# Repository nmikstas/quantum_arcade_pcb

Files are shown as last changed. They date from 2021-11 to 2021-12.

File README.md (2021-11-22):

# quantum_arcade_pcb
Reproduction of the Atari Quantum Arcade PCB. The PCB is designed with Kicad. This project is now complete and verified working!

# Folder Structure
* BOM - Bill of materials
* gerbers - Gerber files
* Quantum_1B_GAL - Design and programming files for the GAL IC located at location 1B
* quantum_arcade_pcb - Kicad design files

# PCB Specifications
* Layers: 2
* Dimensions: 293mm X 531mm
* Different PCB Design: 1
* PCB Thickness: 1.6mm
* Surface Finish: HASL
* Castellated Holes: No
* Copper Weight: 1oz.

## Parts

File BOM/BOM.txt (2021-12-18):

Part_ID                                                              QTY     DESC             Part_Num

R20, R22, R48, R56, R57, R75, R76                                    7       Not Populated   N/A
C5,  C6,  C7,  C22, C23, C24                                         6       Not Populated   N/A
C_9, E_9                                                             2       Not Populated   N/A

C2,   C3,   C9,   C10,  C11,  C14,  C15,  C16,  C17,  C18,           75      .1uf            Digikey 399-4454-1-ND
C19,  C20,  C26,  C27,  C28,  C31,  C33,  C34,  C35,  C36,
C39,  C40,  C49,  C64,  C65,  C67,  C68,  C69,  C70,  C71,
C72,  C73,  C75,  C78,  C79,  C81,  C91,  C92,  C93,  C94,
C95,  C96,  C97,  C98,  C99,  C100, C101, C102, C103, C104,
C105, C106, C107, C108, C109, C110, C111, C112, C113, C114,
C115, C116, C117, C118, C119, C120, C121, C122, C123, C124,
C125, C126, C127, C128, C129
C52,  C53,  C54,  C55,  C56,  C57,  C58,  C59,  C60,  C62,           11      1uf 50V          Digikey 1572-1280-ND
C74
C41,  C83,  C84,  C85,  C86,  C87,  C88,  C89,  C90                  9       .01uf            Digikey 399-4452-1-ND
C13,  C30,  C32,  C76                                                4       100pf            Digikey BC1057CT-ND
C12,  C29,  C38,  C77                                                4       39pf             Digikey P9633-ND
C44,  C46,  C82                                                      3       100uf 35V        Digikey 1572-1309-ND
C45,  C48,  C47                                                      3       22uf 25V         Digikey 1572-1393-ND
C51,  C61                                                            2       1000pf 100V      Digikey 399-4450-1-ND
C8,   C25                                                            2       .047uF           Digikey BC3089-ND
C4                                                                   1       .01uF            Digikey 399-14040-1-ND
C21                                                                  1       .0018uF          Digikey 445-173483-1-ND
C37                                                                  1       150pF            Digikey 399-4213-ND
C42                                                                  1       10pF             Digikey 399-14082-ND
C63                                                                  1       220pf            Digikey 1004PHCT-ND
C80                                                                  1       .022uf           Digikey 399-C412C223K1R5TA-ND
C130                                                                 1       .047uf           Digikey 399-4512-1-ND

CR3, CR4, CR6                                                        3       1N100            Digikey 2368-1N4002-ND
CR1                                                                  1       1N914            Digikey 1N914FS-ND
CR5                                                                  1       1N754A           Digikey 2368-1N754A-ND
CR7                                                                  1       Blue LED         Digikey VAOL-5701SBY4-ND

L2, L3, L4                                                           1       1uH              Digikey M10137-ND
L1                                                                   1       100uH            Digikey 78F101J-TR-RCCT-ND

Q7,  Q9, Q10, Q11, Q13, Q14, Q17                                     7       2N3904           Digikey 2N3904TAFSCT-ND
Q8,  Q12                                                             2       2N3906           Digikey 2N3906TAFSCT-ND
Q15, Q16                                                             2       2N6044           Digikey BDX53BG-ND

R53,  R80,  R82,  R119, R129, R147, R148, R153, R155, R156,          29      1k               Digikey 1.0KQBK-ND
R157, R158, R159, R166, R167, R168, R169, R170, R171, R172,
R176, R205, R210, R214, R218, R219, R220, R221, R222
R40,  R46,  R67,  R73,  R83,  R118, R120, R121, R122, R123,          21      10k              Digikey 10KQBK-ND
R124, R125, R126, R127, R128, R143, R163, R173, R177, R178,
R215
R142, R188, R189, R190, R191, R192, R193, R194, R195, R196,          19      4.7k             Digikey 4.7KQBK-ND
R197, R198, R199, R200, R201, R202, R203, R216, R217
R32,  R33,  R38,  R51,  R59,  R62,  R63, R137, R138, R139,           16      470              Digikey 470KQBK-ND
R149, R151, R152, R160, R161, R162
R36,  R44,  R45,  R50,  R64,  R69,  R70,  R77, R131, R133,           12      2.2k             Digikey 2.2KQBK-ND
R135, R141
R30,  R31,  R58,  R85,  R86,  R89,  R93,  R95,  R96,  R106,          12      7.5K             Digikey 7.50KXBK-ND
R87,  R91
R110, R111, R112, R113, R114, R115, R116, R117, R134, R145           10      3.3k             Digikey 3.3KQBK-ND
R180, R181, R182, R183, R184, R185, R186, R187                       8       100K             Digikey 100KQBK-ND
R204, R206, R207, R208, R209, R211, R212, R213                       8       220k             Digikey 100KQBK-ND
R37,  R39,  R52,  R65,  R66,  R78,  R79,  R97                        8       3.9k             Digikey 3.9KQBK-ND
R90,  R94,  R224, R225, R226                                         5       100              Digikey 100QBK-ND
R42,  R43,  R68,  R72                                                4       10K POT          Digikey 3386P-103-ND‎
R164, R165, R179, R223                                               4       220              Digikey 220QBK-ND
R35,  R54,  R61                                                      3       680              Digikey 680QBK-ND
R26,  R27,  R55                                                      3       820              Digikey 820QBK-ND
R47,  R74                                                            2       2K POT           Digikey 3386P-202-ND‎
R88,  R92                                                            2       200 POT          Digikey 3386P-201LF-ND
R130, R132                                                           2       1.8k             Digikey 1.8kQBK-ND
R34,  R60                                                            2       2.7k             Digikey 2.7kQBK-ND
R41,  R71                                                            2       5.6k             Digikey 5.6kQBK-ND
R81,  R175                                                           2       15K              Digikey 15kQBK-ND
R49                                                                  1       1.5k             Digikey 1.5kQBK-ND
R84                                                                  1       560              Digikey 560QBK-ND
R108                                                                 1       270              Digikey 270QBK-ND
R136                                                                 1       6.8k             Digikey 6.8kQBK-ND
R140                                                                 1       1.2k             Digikey 1.2kQBK-ND
R144                                                                 1       22k              Digikey 22kQBK-ND
R146                                                                 1       510              Digikey 510QBK-ND
R174                                                                 1       68k              Digikey 68kQBK-ND

RV1, RV2                                                             2       VDR              Alan-1 VDR Replacement

SW1, SW2                                                             2       SW_DIP_x08       Digikey 450-1215-ND

TP+15V1,  TP-15V1,  TP+5V01,  TP+5V02, TP+6V81, TPAUD1, TPAUD2,      19      Test Point       Digikey WM6456-ND
TPBLU1,   TPGND1,   TPGND2,   TPGND3,  TPGRN1,  TPRED1, TP12MHZ,
TPRESET1, TPRESET2, TPWDDIS1, TPXOUT1, TPYOUT1

VR1                                                                  1       L7815            Digikey 296-21624-5-ND
VR2                                                                  1       L7915            Digikey 497-7295-5-ND‎

Y1                                                                   1       12.096MHz        Digikey X429-ND

E_2,   E_3,    F_2,    F_3,  H/J_2, H/J_3, K_2, K_3, L_2, L_3        10      8KX8_ROM
D_5,   D_6,    E_5,    E_6,  M_2,   M_3,   N_2, N_3                  8       2KX8_RAM
A_7,   A_8,    B_7,    B_8,  C_7,   C_8                              6       LS194
D/E_4, E/F_4,  P_2,    P_3,  N_1,   P_1                              6       LS245
A_10,  D/E_11, D/E_12, D_10, M/N_12                                  5       TL082
L_5,   M_5,    M_6,    M_7,  R_6                                     5       LS161
B_5,   C_5,    E_7,    P_10, A_5                                     5       LS157
F_8,   L_9,    J_7,    J_8,  D_7                                     5       LS175
B_11,  B_12,   C_11,   C_12                                          4       MC1495L
L_4,   P_5,    R_2,    R_10                                          4       LS74
M_9,   N_9,    E_1,    F_1                                           4       LS244
F_5,   K_7,    K_8                                                   3       LS32
F_6,   H_7,    P_4                                                   3       LS00
M_8,   N_8,    P_9                                                   3       LS191
A_3,   C_3                                                           2       LM324
B_2/3, D_2/3                                                         2       POKEY
B_9,   F/H_9                                                         2       AM6012
B_10,  E_10                                                          2       LF13201
D_1,   H/J_4                                                         2       LS138
F/H_4, J_10                                                          2       LS04
J_4,   P_6                                                           2       LS02
K_6,   K_9                                                           2       LS109
L_8,   N_6                                                           2       S02
R_4,   R_5                                                           2       LS393
N_10,  P_11                                                          2       4584B
D_8,   N_5                                                           2       LS273
B_1                                                                  1       GAL16V8A
B_6                                                                  1       AVG
D_9                                                                  1       DAC_8
F_7                                                                  1       S289
H_5                                                                  1       LS174
H_6                                                                  1       S129             Alan-1 ROM Replacement
H_8                                                                  1       LS399
J_5                                                                  1       S74
J_6                                                                  1       LS42
J_9                                                                  1       LS260
K/L_1                                                                1       68000
K_4                                                                  1       LS08
K_5                                                                  1       LS27
K_10                                                                 1       S86
L_6                                                                  1       LS14
L_7                                                                  1       S260
M_4                                                                  1       06
N_4                                                                  1       S32
N_7                                                                  1       LS164
P_7                                                                  1       LS163
P_8                                                                  1       S04
R_3                                                                  1       X2212

MISC
-------------------
Pastic Tabs                                                          2       Tabs             Digikey RPC1553-ND      
Heatsink                                                             2       Heatsink         Digikey A10756-ND

IC Sockets
-------------------
8  pin    5
14 pin    37
16 pin    36
18 pin    1
20 pin    15
24 pin    9
28 pin    10
40 pin    3
64 pin    1

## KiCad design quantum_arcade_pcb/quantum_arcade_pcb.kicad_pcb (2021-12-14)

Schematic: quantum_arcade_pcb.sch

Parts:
A_3: LM324A; DIP14
A_5: LS157A; DIP16
A_7, A_8: LS194; DIP16
A_10: 082; DIP8
B_1: 137290; DIP20
B_2/3: POKEY; DDIP40
B_5: LS157B; DIP16
B_6: AVG; DDIP40
B_7, B_8: LS194; DIP16
B_9: AM6012; DIP20
B_10: LF13201; DIP16
B_11, B_12: MC1495LB; DIP14
C2, C3, C9, C10, C11, C14, C15, C16, C17, C18, C19, C20, C26, C27, C28, C31, C33, C34, C35, C36, C39, C40: .1uF; GenComp
C4: .01uF; CapSmall
C5, C6, C22, C23: ?; GenComp
C7, C24: ?; CapSmall
C8, C25: .047uF; CapInt
C12, C29: 39pf; CapSmall
C13, C30, C32: 100pf; CapSmall
C21: .0018uF; CapSmall
C37: 150pF; CapSmall
C38: 39pF; CapSmall
C41: .01uF; GenComp
C42: 10pF; CapSmall
C44, C46: 100uf 35V; Cap2
C45, C48: 22uf 25V; Cap1
C47: 22uf 35V; Cap3
C49, C64, C65, C67, C68, C69, C70, C71, C72, C73, C75, C78, C79, C81, C91, C92, C93, C94, C95, C96, C97, C98, C99, C100, C101, C102, C103, C104, C105, C106, C107, C108, C109, C110, C111, C112, C113, C114, C115, C116, C117, C118, C119, C120, C121, C122, C123, C124, C125, C126, C127, C128, C129: .1uf; GenComp
C51, C61: 1000pf 100V; GenComp
C52, C53, C54, C55, C56, C57, C58, C59, C60, C62: 1uf 50V; Cap1
C63: 220pf; GenComp
C74: 1uf; Cap1
C76: 100pf 100V; CapSmall
C77: 39pf 100V; CapSmall
C80: .022uf; GenComp
C82: 100uf 25V; Cap2
C83, C84, C85, C86, C87, C88, C89, C90: .01uf 25V; GenComp
C130: .047uf; GenComp
CR1: 1N914; Diode
CR3, CR4, CR6: 1N100; Diode
CR5: 1N754A; Diode
CR7: LED
C_3: LM324A; DIP14
C_5: LS157B; DIP16
C_7, C_8: LS194; DIP16
C_9: Spare16; DIP16
C_11, C_12: MC1495LA; DIP14
D/E_4: LS245; DIP20
D/E_11, D/E_12: 082; DIP8
D_1: LS138; DIP16
D_2/3: POKEY; DDIP40
D_5, D_6: 2KX8_RAM; DDIP24
D_7: LS175C; DIP16
D_8: LS273; DIP20
D_9: DAC_8; DIP16
D_10: 082; DIP8
E/F_4: LS245; DIP20
E_1: LS244A; DIP20
E_2, E_3: 8KX8_ROM; DIP28
E_5, E_6: 2KX8_RAM; DDIP24
E_7: LS157B; DIP16
E_9: Spare16; DIP16
E_10: LF13201; DIP16
F/H_4: LS04; DIP14
F/H_9: AM6012; DIP20
F_1: LS244B; DIP20
F_2, F_3: 8KX8_ROM; DIP28
F_5: LS32; DIP14
F_6: LS00; DIP14
F_7: S289; DIP16
F_8: LS175; DIP16
H/J_2, H/J_3: 8KX8_ROM; DIP28
H/J_4: LS138; DIP16
H_5: LS174; DIP16
H_6: S129; DIP16
H_7: LS00; DIP14
H_8: LS399; DIP16
J20: J20; EdgeCon
J_4: LS02; DIP14
J_5: S74; DIP14
J_6: LS42; DIP16
J_7: LS175A; DIP16
J_8: LS175B; DIP16
J_9: LS260; DIP14
J_10: LS04; DIP14
K/L_1: 68000; DIP64
K_2, K_3: 8KX8_ROM; DIP28
K_4: LS08; DIP14
K_5: LS27; DIP14
K_6, K_9: LS109; DIP16
K_7, K_8: LS32; DIP14
K_10: S86; DIP14
L1: 100uH; Ind
L2, L3, L4: 1uH; Ind
L_2, L_3: 8KX8_ROM; DIP28
L_4: LS74; DIP14
L_5: LS161; DIP16
L_6: LS14; DIP14
L_7: S260; DIP14
L_8: S02; DIP14
L_9: LS175; DIP16
M/N_12: TL082; DIP8
M_2, M_3: 2KX8_RAM; DDIP24
M_4: 06; DIP14
M_5, M_6, M_7: LS161; DIP16
M_8: LS191A; DIP16
M_9: LS244C; DIP20
N_1: LS245B; DIP20
N_2, N_3: 2KX8_RAM; DDIP24
N_4: S32; DIP14
N_5: LS273B; DIP20
N_6: S02; DIP14
N_7: LS164; DIP14
N_8: LS191A; DIP16
N_9: LS244C; DIP20
N_10: 4584B; DIP14
P_1: LS245A; DIP20
P_2, P_3: LS245C; DIP20
P_4: LS00; DIP14
P_5: LS74; DIP14
P_6: LS02; DIP14
P_7: LS163; DIP16
P_8: S04; DIP14
P_9: LS191A; DIP16
P_10: LS157B; DIP16
P_11: 4584B; DIP14
Q7, Q9, Q10, Q11, Q13, Q14, Q17: 2N3904; GenTrans
Q8, Q12: 2N3906; GenTrans
Q15, Q16: 2N6044; BigTrans
R20, R22, R56, R57: ?; GenComp
R26, R27, R55: 820; GenComp
R30, R31, R58, R85, R86, R89, R93, R95, R96, R106: 7.5K; GenComp
R32, R33, R38, R51, R59, R62, R63, R137, R138, R139, R149, R151, R152, R160, R161, R162: 470; GenComp
R34, R60: 2.7k; GenComp
R35, R54, R61: 680; GenComp
R36, R44, R45, R50, R64, R69, R70, R77, R131, R133, R135, R141: 2.2k; GenComp
R37, R39, R52, R65, R66, R78, R79: 3.9k; GenComp
R40, R46, R67, R73, R118, R120, R121, R122, R123, R124, R125, R126, R127, R128, R143, R163, R173, R177, R178, R215: 10k; GenComp
R41, R71: 5.6k; GenComp
R42, R43, R68, R72: 10k; PotBlk
R47, R74: 2K; PotBlk
R48, R75: 100k; GenComp
R49: 1.5k; GenComp
R53, R80, R119, R129, R147, R148, R153, R155, R156, R157, R158, R159, R166, R167, R168, R169, R170, R171, R172, R176, R205, R210, R214, R218, R219, R220, R221, R222: 1k; GenComp
R76, R140: 1.2k; GenComp
R81: 15K; GenComp
R82: 1K; GenComp
R83: 10K; GenComp
R84: 560; GenComp
R87, R91: 7.5k; GenComp
R88, R92: 200; PotBlk
R90, R94, R224, R225, R226: 100; GenComp
R97: 3.9K; GenComp
R108: 270; CapInt
R110, R111, R112, R113, R114, R115, R116, R117, R134, R145: 3.3k; GenComp
R130, R132: 1.8k; GenComp
R136: 6.8k; GenComp
R142, R188, R189, R190, R191, R192, R193, R194, R195, R196, R197, R198, R199, R200, R201, R202, R203, R216, R217: 4.7k; GenComp
R144: 22k; GenComp
R146: 510; GenComp
R164, R165, R179, R223: 220; GenComp
R174: 68k; GenComp
R175: 15k; GenComp
R180, R181, R182, R183, R184, R185, R186, R187: 100K; GenComp
R204, R206, R207, R208, R209, R211, R212, R213: 220k; GenComp
RV1, RV2: VDR; GenComp
R_2, R_10: LS74; DIP14
R_3: X2212; DIP18
R_4, R_5: LS393; DIP14
R_6: LS161; DIP16
SW1, SW2: SW_DIP_x08; DIP16
TP5V1, TP5V2, TP6.8V1, TP12M1: TP
TP+15V1: TP
TP-15V1: TP
TPAUD1, TPAUD2: TP
TPBLU1: TP
TPGND1, TPGND2, TPGND3: TP
TPGRN1: TP
TPRED1: TP
TPRESET1, TPRESET2: TP
TPWDDIS1: TP
TPXOUT1: TP
TPYOUT1: TP
VR1: L7815_; BigTrans
VR2: L7915_; BigTrans
Y1: 12.096MHz; Crystal

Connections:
1.5M: K_6.3 (K), K_6.13 (K), K_7.9, P_6.12, P_7.12 (QC), P_8.9
1HORIZCLK: C55.2, C85.2, J20.6, R112.2
1HORIZDIR: C53.2, C83.2, J20.H, R110.2
1VERTCLK: C59.2, C89.2, J20.5, R116.2
1VERTDIR: C57.2, C87.2, J20.F, R114.2
2HORIZCLK: C56.2, C86.2, J20.8, R113.2
2HORIZDIR: C54.2, C84.2, J20.C, R111.2
2VERTCLK: C60.2, C90.2, J20.7, R117.2
2VERTDIR: C58.2, C88.2, J20.D, R115.2
3M: L_7.12, N_7.8 (CLK), P_6.11, P_7.13 (QB)
6M: K/L_1.15 (CLK), L_7.3, P_5.3 (1CLK), P_5.11 (2CLK), P_7.14 (QA), R_2.3 (1CLK), R_2.11 (2CLK)
12M: A_7.11 (CK), A_8.11 (CK), B_7.11 (CK), B_8.11 (CK), C_7.11 (CK), C_8.11 (CK), K_6.4 (Cp), K_6.12 (Cp), K_9.4 (Cp), K_9.12 (Cp), L_5.2 (CLK), M_5.2 (CLK), M_6.2 (CLK), M_7.2 (CLK), M_8.14 (CK), P_7.2 (CLK), P_8.10, TP12M1.1, TP12M1.2
750KHZ: P_7.11 (QD), R_5.1 (1CK)
+5V: A_5.16 (VCC), A_7.16 (VCC), A_8.16 (VCC), B_1.20 (Vcc), B_2/3.17 (VCC), B_5.16 (VCC), B_6.37 (VDD), B_7.16 (VCC), B_8.16 (VCC), B_9.20 (VCC), C2.1, C5.2, C19.1, C22.2, C39.1, C71.2, C75.1, C82.1, C96.1, C97.1, C98.1, C99.1, C100.1, C101.1, C102.1, C103.1, C104.1, C105.1, C106.1, C107.1, C108.1, C109.1, C110.1, C111.1, C112.1, C113.1, C114.1, C115.1, C116.1, C117.1, C118.1, C119.1, C120.1, C121.1, C122.1, C123.1, C124.1, C125.1, C126.1, C127.1, C128.1, C129.1, CR6.1 (K), C_5.16 (VCC), C_7.16 (VCC), C_8.16 (VCC), C_9.14, D/E_4.20 (VCC), D_1.16 (VCC), D_2/3.17 (VCC), D_5.24 (VCC), D_6.24 (VCC), D_7.16 (VCC), D_8.20 (VCC), D_9.13 (V+), E/F_4.20 (VCC), E_1.20 (VCC), E_2.1 (VPP), E_2.27 (~PGM), E_2.28 (VCC), E_3.1 (VPP), E_3.27 (~PGM), E_3.28 (VCC), E_5.24 (VCC), E_6.24 (VCC), E_7.16 (VCC), E_9.14, F/H_4.14 (VCC), F/H_9.20 (VCC), F_1.20 (VCC), F_2.1 (VPP), F_2.27 (~PGM), F_2.28 (VCC), F_3.1 (VPP), F_3.27 (~PGM), F_3.28 (VCC), F_5.14 (VCC), F_6.14 (VCC), F_7.16 (VCC), F_8.16 (VCC), H/J_2.1 (VPP), H/J_2.27 (~PGM), H/J_2.28 (VCC), H/J_3.1 (VPP), H/J_3.27 (~PGM), H/J_3.28 (VCC), H/J_4.16 (VCC), H_5.16 (VCC), H_6.16 (VCC), H_7.14 (VCC), H_8.16 (VCC), J20.2, J20.21, J20.B, J20.Y, J_4.14 (VCC), J_5.14 (VCC), J_6.16 (VCC), J_7.16 (VCC), J_8.16 (VCC), J_9.14 (VCC), J_10.14 (VCC), K/L_1.14 (VCC), K/L_1.49 (VCC), K_2.1 (VPP), K_2.27 (~PGM), K_2.28 (VCC), K_3.1 (VPP), K_3.27 (~PGM), K_3.28 (VCC), K_4.14 (VCC), K_5.14 (VCC), K_6.16 (VCC), K_7.14 (VCC), K_8.14 (VCC), K_9.16 (VCC), K_10.14 (VCC), L_2.1 (VPP), L_2.27 (~PGM), L_2.28 (VCC), L_3.1 (VPP), L_3.27 (~PGM), L_3.28 (VCC), L_4.14 (VCC), L_5.16 (VCC), L_6.14 (VCC), L_7.14 (VCC), L_8.14 (VCC), L_9.16 (VCC), M/N_12.2 (-), M_2.24 (VCC), M_3.24 (VCC), M_4.14 (VCC), M_5.16 (VCC), M_6.16 (VCC), M_7.16 (VCC), M_8.16 (VCC), M_9.20 (VCC), N_1.20 (VCC), N_2.24 (VCC), N_3.24 (VCC), N_4.14 (VCC), N_5.20 (VCC), N_6.14 (VCC), N_7.14 (VCC), N_8.16 (VCC), N_9.20 (VCC), N_10.14 (VCC), P_1.20 (VCC), P_2.20 (VCC), P_3.20 (VCC), P_4.14 (VCC), P_5.14 (VCC), P_6.14 (VCC), P_7.16 (VCC), P_8.14 (VCC), P_9.16 (VCC), P_10.16 (VCC), P_11.14 (VCC), Q13.3 (C), Q17.3 (C), R145.2, R146.2, R149.2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
+6V: B_11.1, B_12.1, C32.1, C49.1, CR5.1 (K), C_11.1, C_12.1, R108.1, TP6.8V1.1, TP6.8V1.2
+10V: C74.1, J20.18, J20.E, M/N_12.8 (V+), R173.2
+15V: A_3.4 (V+), A_10.8 (VCC), B_10.13, B_11.2, B_12.2, C9.2, C11.2, C15.2, C18.1, C26.2, C28.2, C33.2, C36.1, C45.1, C92.1, C94.1, CR3.1 (K), C_3.4 (V+), D/E_11.8 (VCC), D/E_12.8 (VCC), D_10.8 (VCC), E_10.13, Q8.1 (E), R44.2, R45.2, R53.1, R69.2, R70.2, R80.1, R82.2, R95.1, R96.1, R108.2, TP+15V1.1, TP+15V1.2, VR1.3 (OUT)
+24V: C44.1, J20.3, J20.X, VR1.1 (IN)
-15V: A_3.11 (V-), A_10.4 (VSS), B_9.17 (V-), B_10.4, B_11.7, B_12.7, C3.2, C6.2, C10.2, C14.2, C16.2, C17.1, C20.2, C23.2, C27.2, C31.2, C34.2, C35.1, C40.1, C41.1, C48.2, C91.1, C93.1, CR4.2 (A), C_3.11 (V-), C_9.1, C_11.7, C_12.7, D/E_11.4 (VSS), D/E_12.4 (VSS), D_9.3 (V-), D_10.4 (VSS), E_9.1, E_10.4, F/H_9.17 (V-), TP-15V1.1, TP-15V1.2, VR2.3 (VO)
-24V: C46.2, C47.2, J20.4, J20.W, VR2.2 (VI)
A1: E_1.13 (I1b), K/L_1.29 (A1)
A2: E_1.11 (I0b), K/L_1.30 (A2)
A3: F_1.13 (I1b), K/L_1.31 (A3)
A4: F_1.11 (I0b), K/L_1.32 (A4)
A5: E_1.2 (I0a), K/L_1.33 (A5)
A6: F_1.2 (I0a), K/L_1.34 (A6)
A7: E_1.17 (I3b), K/L_1.35 (A7)
A8: E_1.4 (I1a), K/L_1.36 (A8)
A9: F_1.4 (I1a), K/L_1.37 (A9)
A10: F_1.17 (I3b), K/L_1.38 (A10)
A11: E_1.15 (I2b), K/L_1.39 (A11)
A12: F_1.6 (I2a), K/L_1.40 (A12)
A13: E_1.6 (I2a), K/L_1.41 (A13)
A14: F_1.15 (I2b), K/L_1.42 (A14)
A15: F_1.8 (I3a), K/L_1.43 (A15)
A16: D_1.3 (C), H/J_4.2 (B), K/L_1.44 (A16)
A17: H/J_4.3 (C), K/L_1.45 (A17)
A18: B_1.7, K/L_1.46 (A18)
A19: B_1.6, K/L_1.47 (A19)
A20: B_1.5, K/L_1.48 (A20)
A21: B_1.4, K/L_1.50 (A21)
A22: B_1.3, D_1.5 (~G2B), K/L_1.51 (A22)
A23: B_1.2, D_1.4 (~G2A), K/L_1.52 (A23), N_4.1
AB1: B_2/3.36 (A0), C_5.14 (4A), D_2/3.36 (A0), E_1.7 (O1b), E_2.10 (A0), E_3.10 (A0), E_7.14 (4A), F_2.10 (A0), F_3.10 (A0), H/J_2.10 (A0), H/J_3.10 (A0), K_2.10 (A0), K_3.10 (A0), L_2.10 (A0), L_3.10 (A0), M_2.8 (A0), M_3.8 (A0), N_2.8 (A0), N_3.8 (A0), R_3.6 (A0)
AB2: B_2/3.35 (A1), C_5.11 (3A), D_2/3.35 (A1), E_1.9 (O0b), E_2.9 (A1), E_3.9 (A1), E_7.11 (3A), F_2.9 (A1), F_3.9 (A1), H/J_2.9 (A1), H/J_3.9 (A1), K_2.9 (A1), K_3.9 (A1), L_2.9 (A1), L_3.9 (A1), M_2.7 (A1), M_3.7 (A1), N_2.7 (A1), N_3.7 (A1), R_3.5 (A1)
AB3: B_2/3.34 (A2), C_5.5 (2A), D_2/3.34 (A2), E_2.8 (A2), E_3.8 (A2), E_7.5 (2A), F_1.7 (O1b), F_2.8 (A2), F_3.8 (A2), H/J_2.8 (A2), H/J_3.8 (A2), K_2.8 (A2), K_3.8 (A2), L_2.8 (A2), L_3.8 (A2), M_2.6 (A2), M_3.6 (A2), N_2.6 (A2), N_3.6 (A2), R_3.4 (A2)
AB4: B_2/3.33 (A3), C_5.2 (1A), D_2/3.33 (A3), E_2.7 (A3), E_3.7 (A3), E_7.2 (1A), F_1.9 (O0b), F_2.7 (A3), F_3.7 (A3), H/J_2.7 (A3), H/J_3.7 (A3), K_2.7 (A3), K_3.7 (A3), L_2.7 (A3), L_3.7 (A3), M_2.5 (A3), M_3.5 (A3), N_2.5 (A3), N_3.5 (A3), R_3.3 (A3)
AB5: B_5.14 (4A), D_2/3.30 (~CSO), E_1.18 (O0a), E_2.6 (A4), E_3.6 (A4), F/H_4.9, F_2.6 (A4), F_3.6 (A4), H/J_2.6 (A4), H/J_3.6 (A4), K_2.6 (A4), K_3.6 (A4), L_2.6 (A4), L_3.6 (A4), M_2.4 (A4), M_3.4 (A4), N_2.4 (A4), N_3.4 (A4), R_3.2 (A4)
AB6: B_5.11 (3A), E_2.5 (A5), E_3.5 (A5), F_1.18 (O0a), F_2.5 (A5), F_3.5 (A5), H/J_2.5 (A5), H/J_3.5 (A5), K_2.5 (A5), K_3.5 (A5), L_2.5 (A5), L_3.5 (A5), M_2.3 (A5), M_3.3 (A5), N_2.3 (A5), N_3.3 (A5), R_3.1 (A5)
AB7: B_5.5 (2A), E_1.3 (O3b), E_2.4 (A6), E_3.4 (A6), F_2.4 (A6), F_3.4 (A6), H/J_2.4 (A6), H/J_3.4 (A6), K_2.4 (A6), K_3.4 (A6), L_2.4 (A6), L_3.4 (A6), M_2.2 (A6), M_3.2 (A6), N_2.2 (A6), N_3.2 (A6), R_3.17 (A6)
AB8: B_5.2 (1A), E_1.16 (O1a), E_2.3 (A7), E_3.3 (A7), F_2.3 (A7), F_3.3 (A7), H/J_2.3 (A7), H/J_3.3 (A7), K_2.3 (A7), K_3.3 (A7), L_2.3 (A7), L_3.3 (A7), M_2.1 (A7), M_3.1 (A7), N_2.1 (A7), N_3.1 (A7), R_3.16 (A7)
AB9: A_5.14 (4A), E_2.25 (A8), E_3.25 (A8), F_1.16 (O1a), F_2.25 (A8), F_3.25 (A8), H/J_2.25 (A8), H/J_3.25 (A8), K_2.25 (A8), K_3.25 (A8), L_2.25 (A8), L_3.25 (A8), M_2.23 (A8), M_3.23 (A8), N_2.23 (A8), N_3.23 (A8)
AB10: A_5.2 (1A), E_2.24 (A9), E_3.24 (A9), F_1.3 (O3b), F_2.24 (A9), F_3.24 (A9), H/J_2.24 (A9), H/J_3.24 (A9), K_2.24 (A9), K_3.24 (A9), L_2.24 (A9), L_3.24 (A9), M_2.22 (A9), M_3.22 (A9), N_2.22 (A9), N_3.22 (A9)
AB11: A_5.5 (2A), E_1.5 (O2b), E_2.21 (A10), E_3.21 (A10), F_2.21 (A10), F_3.21 (A10), H/J_2.21 (A10), H/J_3.21 (A10), K_2.21 (A10), K_3.21 (A10), L_2.21 (A10), L_3.21 (A10), M_2.19 (A10), M_3.19 (A10), N_2.19 (A10), N_3.19 (A10)
AB12: A_5.11 (3A), E_2.23 (A11), E_3.23 (A11), F_1.14 (O2a), F_2.23 (A11), F_3.23 (A11), H/J_2.23 (A11), H/J_3.23 (A11), K_2.23 (A11), K_3.23 (A11), L_2.23 (A11), L_3.23 (A11)
AB13: E_1.14 (O2a), E_2.2 (A12), E_3.2 (A12), F_2.2 (A12), F_3.2 (A12), H/J_2.2 (A12), H/J_3.2 (A12), K_2.2 (A12), K_3.2 (A12), L_2.2 (A12), L_3.2 (A12)
AB14: D_1.1 (A), F_1.5 (O2b)
AB15: D_1.2 (B), F_1.12 (O3a), H/J_4.1 (A)
AM1: C_5.12 (4Y), D_5.8 (A0), D_6.8 (A0), E_5.8 (A0), E_6.8 (A0)
AM2: C_5.9 (3Y), D_5.7 (A1), D_6.7 (A1), E_5.7 (A1), E_6.7 (A1)
AM3: C_5.7 (2Y), D_5.6 (A2), D_6.6 (A2), E_5.6 (A2), E_6.6 (A2)
AM4: C_5.4 (1Y), D_5.5 (A3), D_6.5 (A3), E_5.5 (A3), E_6.5 (A3)
AM5: B_5.12 (4Y), D_5.4 (A4), D_6.4 (A4), E_5.4 (A4), E_6.4 (A4)
AM6: B_5.9 (3Y), D_5.3 (A5), D_6.3 (A5), E_5.3 (A5), E_6.3 (A5)
AM7: B_5.7 (2Y), D_5.2 (A6), D_6.2 (A6), E_5.2 (A6), E_6.2 (A6)
AM8: B_5.4 (1Y), D_5.1 (A7), D_6.1 (A7), E_5.1 (A7), E_6.1 (A7)
AM9: A_5.12 (4Y), D_5.23 (A8), D_6.23 (A8), E_5.23 (A8), E_6.23 (A8)
AM10: A_5.4 (1Y), D_5.22 (A9), D_6.22 (A9), E_5.22 (A9), E_6.22 (A9)
AM11: A_5.7 (2Y), D_5.19 (A10), D_6.19 (A10), E_5.19 (A10), E_6.19 (A10)
AREF: A_3.5 (+), C78.2, C_3.10 (+), R204.2
AS: D_1.6 (G1), F/H_4.2, P_5.10 (~1PRE_), R_2.10 (~1PRE_)
AUDIO+: A_3.8, J20.13, R207.1, R208.2, TPAUD1.1, TPAUD1.2
BLUE: J20.17, R225.2, TPBLU1.1, TPBLU1.2
CNTR: K_7.4, K_9.6 (Q), L_7.11
COINAUX: J20.L, R159.2, R162.1
COINCONTL: C72.1, J20.15, Q15.2 (C)
COINCONTR: C73.1, J20.S, Q16.2 (C)
COINL: J20.J, R151.1, R155.2
COINR: J20.9, R152.1, R156.2
CS: B_2/3.31 (CS), D_2/3.31 (CS), J_4.10
D0: K/L_1.5 (D0), N_1.15 (B3)
D1: K/L_1.4 (D1), N_1.14 (B4)
D2: K/L_1.3 (D2), N_1.13 (B5)
D3: K/L_1.2 (D3), N_1.12 (B6)
D4: K/L_1.1 (D4), N_1.11 (B7)
D5: K/L_1.64 (D5), N_1.18 (B0)
D6: K/L_1.63 (D6), N_1.17 (B1)
D7: K/L_1.62 (D7), N_1.16 (B2)
D8: K/L_1.61 (D8), P_1.18 (B0)
D9: K/L_1.60 (D9), P_1.17 (B1)
D10: K/L_1.59 (D10), P_1.16 (B2)
D11: K/L_1.58 (D11), P_1.15 (B3)
D12: K/L_1.57 (D12), P_1.14 (B4)
D13: K/L_1.56 (D13), P_1.13 (B5)
D14: K/L_1.55 (D14), P_1.12 (B6)
D15: K/L_1.54 (D15), P_1.11 (B7)
DB0: B_2/3.38 (D0), D/E_4.11 (B7), D_2/3.38 (D0), F_7.4 (I0), M_9.14 (O2a), N_1.5 (A3), N_5.8 (D3), N_9.14 (O2a), P_3.16 (B2), R_3.12 (IO1)
DB1: B_2/3.39 (D1), D/E_4.12 (B6), D_2/3.39 (D1), F_7.6 (I1), M_9.12 (O3a), N_1.6 (A4), N_5.3 (D0), N_9.12 (O3a), P_3.14 (B4), R_3.13 (IO2)
DB2: B_2/3.40 (D2), D/E_4.13 (B5), D_2/3.40 (D2), F_7.10 (I2), M_9.16 (O1a), N_1.7 (A5), N_5.7 (D2), N_9.16 (O1a), P_3.12 (B6), R_3.14 (IO3)
DB3: B_2/3.2 (D3), D/E_4.14 (B4), D_2/3.2 (D3), F_7.12 (I3), M_9.18 (O0a), N_1.8 (A6), N_5.4 (D1), N_9.18 (O0a), P_3.11 (B7), R_3.15 (IO4)
DB4: B_2/3.3 (D4), D/E_4.15 (B3), D_2/3.3 (D4), M_9.5 (O2b), N_1.9 (A7), N_5.14 (D5), N_9.5 (O2b), P_3.13 (B5)
DB5: B_2/3.4 (D5), D/E_4.16 (B2), D_2/3.4 (D5), M_9.3 (O3b), N_1.2 (A0), N_5.13 (D4), N_9.3 (O3b), P_3.15 (B3)
DB6: B_2/3.5 (D6), D/E_4.17 (B1), D_2/3.5 (D6), M_9.7 (O1b), N_1.3 (A1), N_5.18 (D7), N_9.7 (O1b), P_3.17 (B1)
DB7: B_2/3.6 (D7), D/E_4.18 (B0), D_2/3.6 (D7), M_9.9 (O0b), N_1.4 (A2), N_5.17 (D6), N_9.9 (O0b), P_3.18 (B0)
DB8: E/F_4.11 (B7), P_1.2 (A0), P_2.16 (B2)
DB9: E/F_4.12 (B6), P_1.3 (A1), P_2.14 (B4)
DB10: E/F_4.13 (B5), P_1.4 (A2), P_2.12 (B6)
DB11: E/F_4.14 (B4), P_1.5 (A3), P_2.11 (B7)
DB12: E/F_4.15 (B3), P_1.6 (A4), P_2.13 (B5)
DB13: E/F_4.16 (B2), P_1.7 (A5), P_2.15 (B3)
DB14: E/F_4.17 (B1), P_1.8 (A6), P_2.17 (B1)
DB15: E/F_4.18 (B0), P_1.9 (A7), P_2.18 (B0)
DVG0: A_7.6 (D), A_8.6 (D), D/E_4.9 (A7), D_5.9 (D0), D_6.9 (D0)
DVG1: A_7.5 (C), A_8.5 (C), D/E_4.8 (A6), D_5.10 (D1), D_6.10 (D1)
DVG2: A_7.4 (B), A_8.4 (B), D/E_4.7 (A5), D_5.11 (D2), D_6.11 (D2)
DVG3: A_7.3 (A), A_8.3 (A), D/E_4.6 (A4), D_5.13 (D3), D_6.13 (D3)
DVG4: C_7.6 (D), C_8.6 (D), D/E_4.5 (A3), D_5.14 (D4), D_6.14 (D4)
DVG5: C_7.5 (C), C_8.5 (C), D/E_4.4 (A2), D_5.15 (D5), D_6.15 (D5)
DVG6: C_7.4 (B), C_8.4 (B), D/E_4.3 (A1), D_5.16 (D6), D_6.16 (D6)
DVG7: C_7.3 (A), C_8.3 (A), D/E_4.2 (A0), D_5.17 (D7), D_6.17 (D7)
DVG8: B_7.6 (D), B_8.6 (D), E/F_4.9 (A7), E_5.9 (D0), E_6.9 (D0)
DVG9: B_7.5 (C), B_8.5 (C), E/F_4.8 (A6), E_5.10 (D1), E_6.10 (D1)
DVG10: B_7.4 (B), B_8.4 (B), E/F_4.7 (A5), E_5.11 (D2), E_6.11 (D2)
DVG11: B_7.3 (A), B_8.3 (A), E/F_4.6 (A4), E_5.13 (D3), E_6.13 (D3)
DVG12: E/F_4.5 (A3), E_5.14 (D4), E_6.14 (D4), J_7.4 (D0), J_8.5 (D1)
DVG13: E/F_4.4 (A2), E_5.15 (D5), E_6.15 (D5), J_7.12 (D2), J_8.12 (D2)
DVG14: E/F_4.3 (A1), E_5.16 (D6), E_6.16 (D6), J_7.13 (D3), J_8.13 (D3)
DVG15: E/F_4.2 (A0), E_5.17 (D7), E_6.17 (D7), J_7.5 (D1), J_8.4 (D0)
DVX2: A_8.14 (QB), B_9.11 (B11), C_9.13
DVX3: A_8.15 (QA), B_9.10 (B10), C_8.7 (L), C_9.12
DVX4: B_9.9 (B9), C_8.12 (QD), C_9.11
DVX5: B_9.8 (B8), C_8.13 (QC), C_9.10
DVX6: B_9.7 (B7), C_8.14 (QB), C_9.9
DVX7: B_8.7 (L), B_9.6 (B6), C_8.15 (QA), C_9.8
DVX8: B_8.12 (QD), B_9.5 (B5), C_9.7
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

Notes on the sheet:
POWER INPUT
CLOCK
POWER-ON RESET AND WATCHDOG
MICROPROCESSOR
ADDRESS BUS BUFFERS
BIDIRECTIONAL DATA BUS BUFFERS
ADDRESS DECODERS
PROGRAM RAM
DATA TRANSFER ACK GENERATOR
CHECK THIS!!!
PROGRAM ROM
Y-Axis Output
NOT LOADED
X-Axis Output
DAC Reference And Bipolar Current Sources
COIN DOOR AND CONTROL PANEL INPUT
TRACK BALL INPUT
NON-VOLATILE MEMORY
COIN DOOR AND CONTROL PANEL OUTPUT
AUDIO OUTPUT
COLOR MEMORY AND OUTPUT
VECTOR MEMORY ARBITRATOR
VECTOR MEMORY
BIDIRECTIONAL VECTOR MEMORY DATA BUFFERS
VECTOR DATA SHIFTERS
OPCODE AND INTENSITY LATCHES
VECTOR ADDRESS CONTROLLER
STATE MACHINE
Z INTENSITY
VECTOR TIMER
INTENSITY CORRECTION
VECTOR HALT FLAG
VECTOR FLAG
CENTER FLAG
NORMALIZATION FLAG
VECTOR SCALING
UNUSED

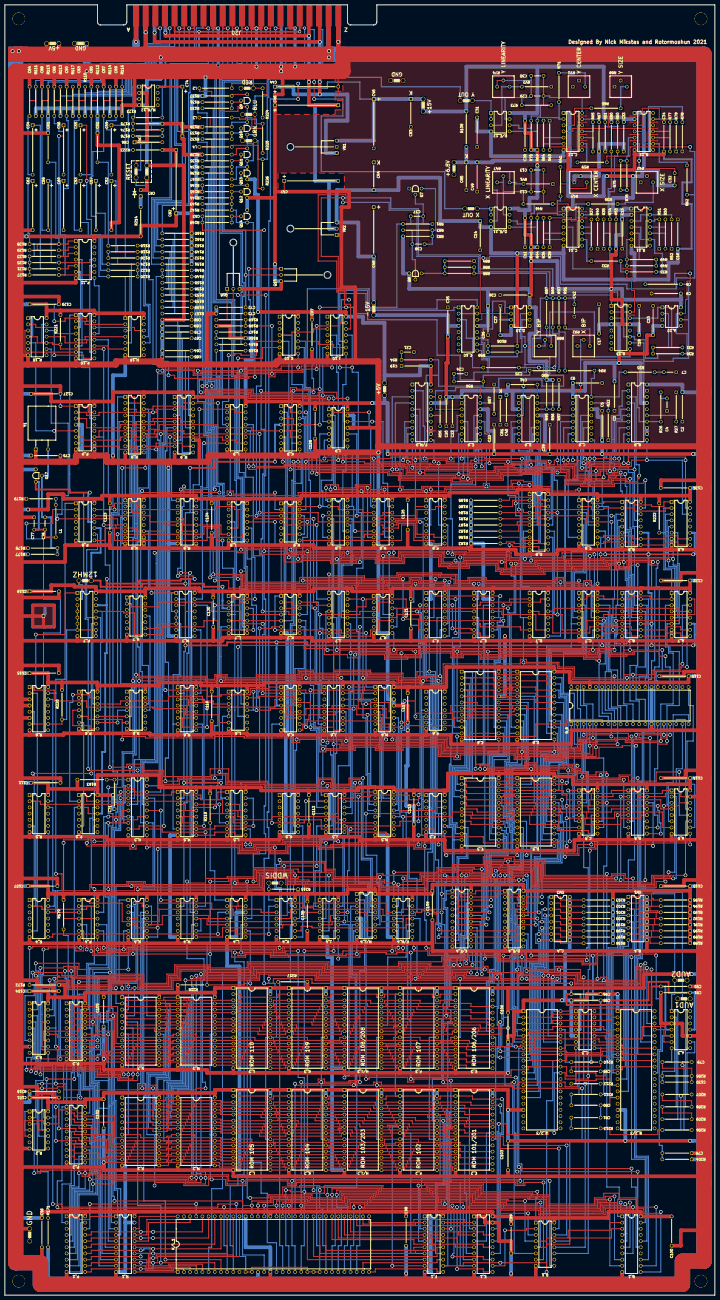
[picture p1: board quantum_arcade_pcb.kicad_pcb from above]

Board: 2 copper layers, 292.1 x 530.9 mm, 482 parts (0 on the bottom side), 568 nets.

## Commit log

2021-07-28 Initial commit. Set up repository. Did initial project work
    [quantum_arcade_pcb.kicad_pcb, quantum_arcade_pcb.sch]
2021-07-29 Finished the first 2 pages of schematics
    [quantum_arcade_pcb.sch]
2021-07-30 Worked on schematic
    [quantum_arcade_pcb.sch]
2021-07-31 added schematic stuff
    [quantum_arcade_pcb.sch]
2021-08-02 Completed 5 schematic pages out of 14
    [Vector_Sheet_1.sch, file6246D615.sch, file638E8E87.sch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]
2021-08-03 Completed 6 schematic pages out of 14
    [quantum_arcade_pcb.sch]
2021-08-05 Completed 8 pages of schematics
    [quantum_arcade_pcb.sch]
2021-08-06 Completed 9 pages of schematics
    [quantum_arcade_pcb.sch]
2021-08-07 Completed 10 pages of schematics
    [quantum_arcade_pcb.sch]
2021-08-08 Finished 13 of 14 schematic pages
    [quantum_arcade_pcb.sch]
2021-08-09 Finished initial schematic
    [quantum_arcade_pcb.sch]
2021-08-09 Fixed all schematic errors
    [quantum_arcade_pcb.sch]
2021-08-10 Placed all ICs on the PCB
    [quantum_arcade_pcb.sch]
2021-08-10 Placed several components
    [quantum_arcade_pcb.kicad_pcb, quantum_arcade_pcb.sch]
2021-08-11 133 components left to place
    [quantum_arcade_pcb.kicad_pcb, quantum_arcade_pcb.sch]
2021-08-11 80 components left to place
    [quantum_arcade_pcb.kicad_pcb, quantum_arcade_pcb.sch]
2021-08-12 50 components left to place
    [quantum_arcade_pcb.kicad_pcb, quantum_arcade_pcb.sch]
2021-08-13 25 components left to place
    [quantum_arcade_pcb.kicad_pcb, quantum_arcade_pcb.sch]
2021-08-15 Finished placing components
    [quantum_arcade_pcb.kicad_pcb, quantum_arcade_pcb.sch]
2021-08-17 1498 disconnected signals remain
    [quantum_arcade_pcb.kicad_pcb, quantum_arcade_pcb.sch]
2021-08-18 Added more traces
    [quantum_arcade_pcb.kicad_pcb]
2021-08-18 1394 disconnected signals remain
    [quantum_arcade_pcb.kicad_pcb]
2021-08-23 1110 unconnected signals remain
    [quantum_arcade_pcb.kicad_pcb]
2021-09-03 Added more signal traces
    [quantum_arcade_pcb.kicad_pcb, quantum_arcade_pcb.sch]
2021-09-07 Added ground plane, 786 disconnected signals remain
    [quantum_arcade_pcb.kicad_pcb, quantum_arcade_pcb.sch]
2021-09-08 592 disconnedted signals remain
    [quantum_arcade_pcb.kicad_pcb, quantum_arcade_pcb.sch]
2021-09-10 542 disconnedted signals remain
    [quantum_arcade_pcb.kicad_pcb]
2021-09-10 495 disconnedted signals remain
    [quantum_arcade_pcb.kicad_pcb]
2021-09-11 388 disconnedted signals remain
    [quantum_arcade_pcb.kicad_pcb]
2021-09-13 295 disconnedted signals remain
    [quantum_arcade_pcb.kicad_pcb, quantum_arcade_pcb.sch]
2021-09-13 208 disconnedted signals remain
    [quantum_arcade_pcb.kicad_pcb, quantum_arcade_pcb.sch]
2021-09-15 84 disconnected signals remain
    [quantum_arcade_pcb.kicad_pcb, quantum_arcade_pcb.sch]
2021-09-15 All signals connected
    [quantum_arcade_pcb.kicad_pcb, quantum_arcade_pcb.sch]
2021-09-26 Added gerbers
    [quantum_arcade_pcb-B_Cu.gbr, quantum_arcade_pcb-B_Mask.gbr, quantum_arcade_pcb-B_SilkS.gbr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]
2021-10-13 Added filed for the 1B IC
    [quantum_arcade_pcb-B_Cu.gbr, quantum_arcade_pcb-B_Mask.gbr, quantum_arcade_pcb-B_SilkS.gbr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]
2021-10-30 Fixed silkscreen issues and connected pin 1 of 7J to pullup
    [quantum_arcade_pcb.kicad_pcb, quantum_arcade_pcb.sch]
2021-11-05 Made final PCB changes
    [quantum_arcade_pcb.kicad_pcb]
2021-11-06 Updated gerbers
    [quantum_arcade_pcb-B_Cu.gbr, quantum_arcade_pcb-B_Mask.gbr, quantum_arcade_pcb-B_SilkS.gbr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]
2021-11-22 Updated the readme file
    [quantum_arcade_pcb-B_Cu.gbr, quantum_arcade_pcb-B_Mask.gbr, quantum_arcade_pcb-B_SilkS.gbr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]
2021-11-28 Began working on the BOM
2021-11-29 Worked on the BOM
2021-12-14 Updated BOM
    [quantum_arcade_pcb.kicad_pcb, quantum_arcade_pcb.sch]
